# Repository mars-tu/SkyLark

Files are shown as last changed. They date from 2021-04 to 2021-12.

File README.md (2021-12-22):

# SkyLark
Repository of Drone named SkyLark by MARS capable of autonomous navigation for transfer of goods.

## Key Feature:-
* Autonomous robot with payload to carry for multiple purposes which is capable to move on RC control.
* Manipulate flight by gesture recognition.
* Runs on PX4 AutoPilot framework via ROS.

## Electro-mechanical design:

* Drone frame.
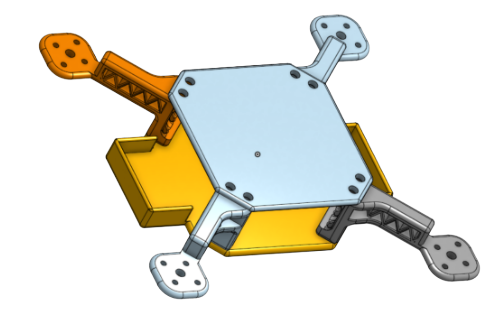
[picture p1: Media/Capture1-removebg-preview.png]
Image alt text Drone frame


## Flight Controller Schematic:
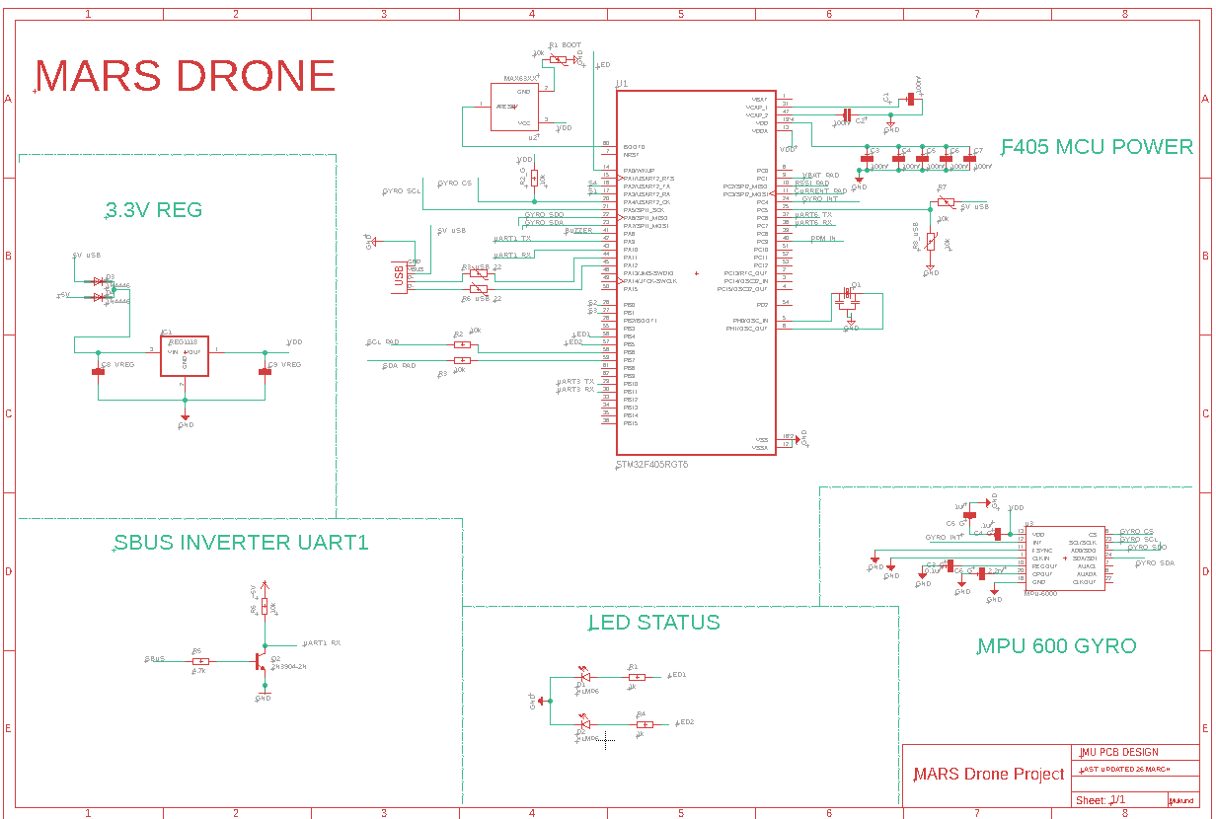
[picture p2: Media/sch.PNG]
Image alt text Schematic


## ROS Packages:
* [SkyLark package](#flying_skylark)

### flying_skylark
------------------
* This package contains all the files related to robot and its configuration 

### Setup and launching the simulation environment:-

* Clone the repo, build in your preferred system and add the following lines in your bashrc.
```
source ~/{name_of_workspace}/devel/setup.bash

source ~/{name_of_workspace}/src/PX4-Autopilot/Tools/setup_gazebo.bash ~/{name_of_workspace}/src/PX4-Autopilot/ ~/{name_of_workspace}/src/PX4-Autopilot/build/px4_sitl_default >> /dev/null

export ROS_PACKAGE_PATH=$ROS_PACKAGE_PATH:~/{name_of_workspace}/src/PX4-Autopilot

export ROS_PACKAGE_PATH=$ROS_PACKAGE_PATH:~/{name_of_workspace}/src/PX4-Autopilot/Tools/sitl_gazebo

```
* For making gazebo work with PX-4 autopilot 
```
cd ~/{name_of_workspace}/src/PX4-Autopilot/
make px4_sitl_default gazebo
```

* Command `roslaunch flying_skylark flying_square.launch` will launch the gazebo world along with the PX-4 autopilot.

### Simulation Video
Click on Image to play
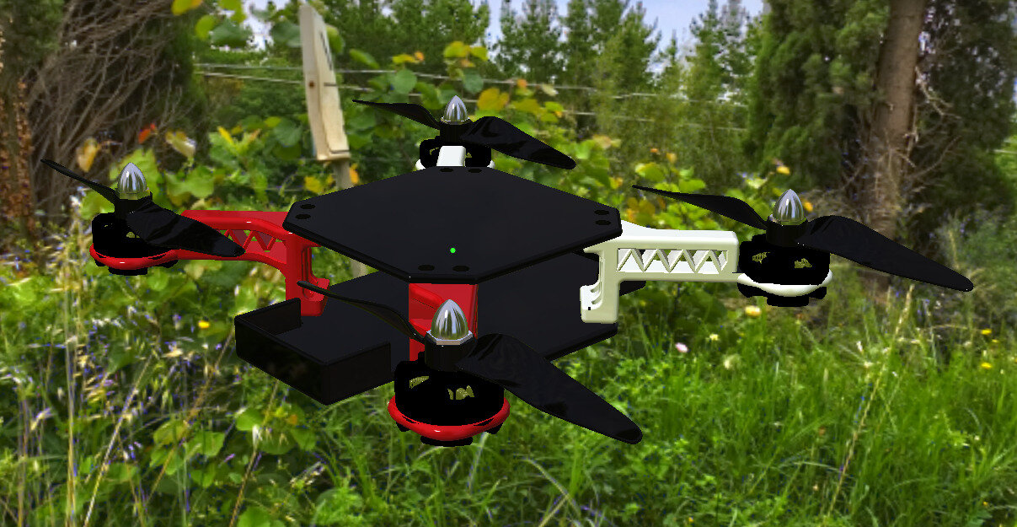
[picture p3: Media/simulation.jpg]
Watch the video (https://drive.google.com/file/d/1lU4UtkTPGOdcDK2UvRqbzy2OsXT-8WxJ/view?usp=sharing)


## Prerequisites
* C++14
* python 2.x
* PX4 AutoPilot
* ROS Noetic
* Embedded C
* Raspberry pi 3B (setup given below)
* Eagle
* PTC Creo
#### Note: Hardware prerequisites mentioned in xyz section.

## Setup
* [Raspi + OS setup](#setting-up-cpu)

### Setting Up CPU
------------------
#### Installing Ubuntu and ROS on Raspberry pi
1) [Download](https://cdimage.ubuntu.com/releases/18.04/release/) the Ubuntu image for raspberry pi 3.
2) Flash the image with preferable software.
3) Follow the standard ARM installation instructions from [ROS Wiki](https://wiki.ros.org/melodic/Installation/Ubuntu) to install ROS Melodic.

#### Installing basic tools and setting them up
```
sudo apt-get update
sudo apt-get upgrade
sudo apt autoremove
```

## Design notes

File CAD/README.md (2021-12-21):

## ITERATION 1:

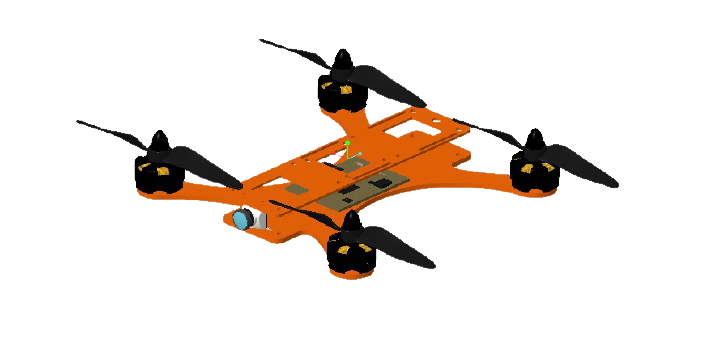
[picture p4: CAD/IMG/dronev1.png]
Image alt text Drone frame 1st Iteration


Flaws in Iteration 1 are: 
1. If the drone were to drop for a height, the whole would get damaged and will have to be replaced making it cost ineffective. 
2. There isn't enough space for electronics components.

## Analysis of Model 1:
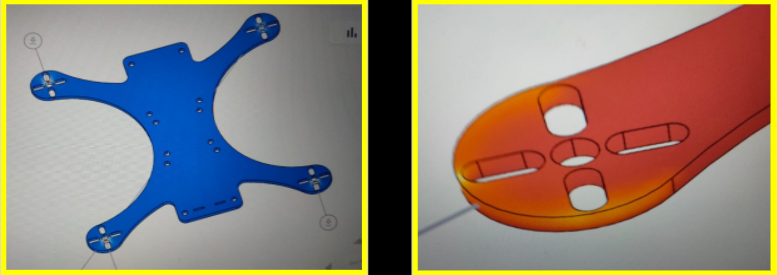
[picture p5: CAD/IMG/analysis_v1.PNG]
Image alt text Drone frame 1 Analysis


## ITERATION 2:

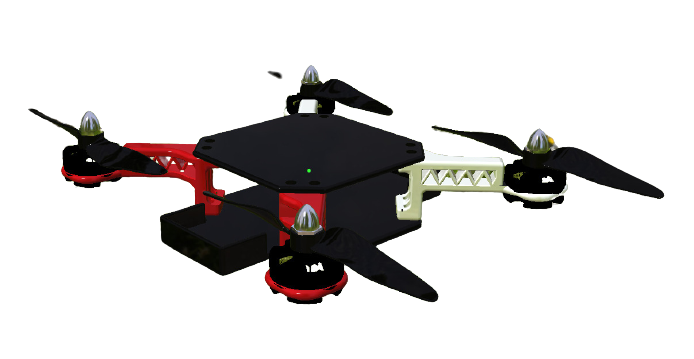
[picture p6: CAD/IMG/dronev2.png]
Image alt text Drone frame 2nd Iteration


Flaws in Iteration 2 are:
1. There can be more optimisation in weight done.
2. Final analysis isn't complete such as drop test and cfd.

## Analysis of Model 1:

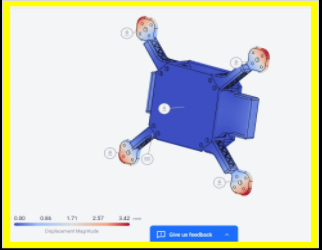
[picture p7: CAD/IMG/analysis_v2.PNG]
Image alt text Drone frame 2 Analysis


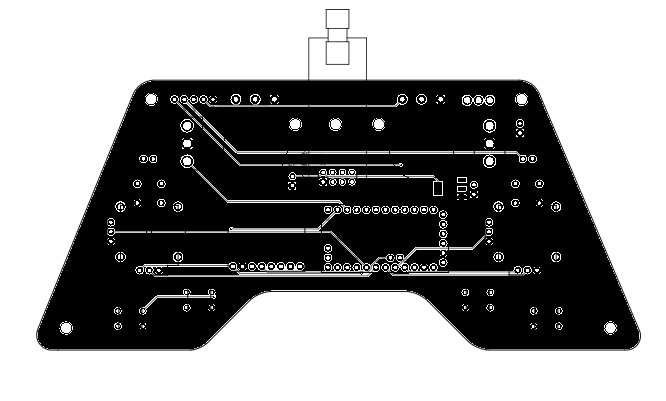
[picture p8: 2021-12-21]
Electronics/Control Unit/Transmitter V2/PCB_Transmitter V2_2021-06-21.png

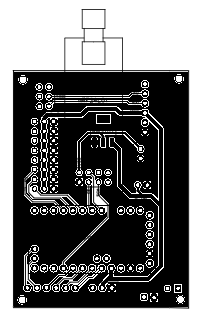
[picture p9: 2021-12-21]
Electronics/Control Unit/Reciver/PCB_Reciver v1_2021-06-21.png

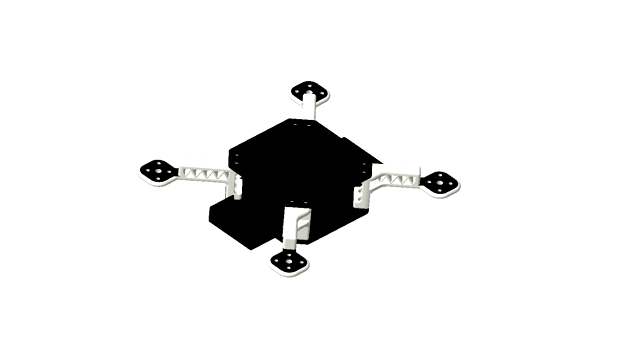
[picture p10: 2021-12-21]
Media/FRAME_V2.gif

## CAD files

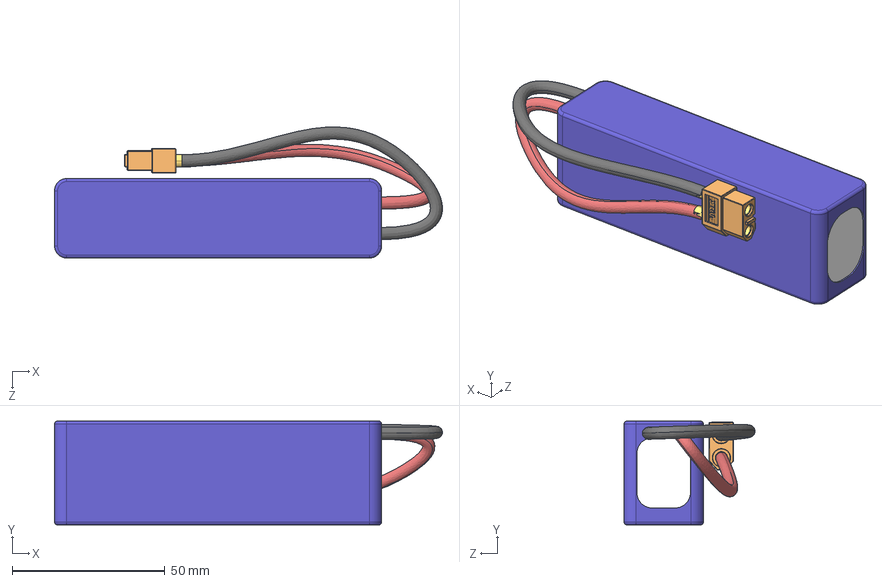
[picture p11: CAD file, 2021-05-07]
CAD/Initial Basic Parts/Assembly_Multistar_Battery_3000mah.STEP
126.9 x 34.0 x 42.9 mm
Multistar_3000mAh_4S_Lipo_Battery
XT60 Buchse
Part3^Assembly_Multistar_Battery_3000mah

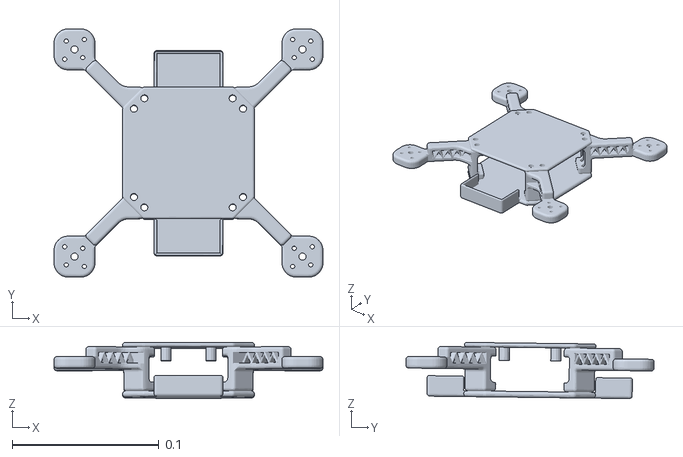
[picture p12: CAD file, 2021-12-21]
src/skylark/flying_skylark/meshes/base_link.STL
0.184 x 0.169 x 0.0383

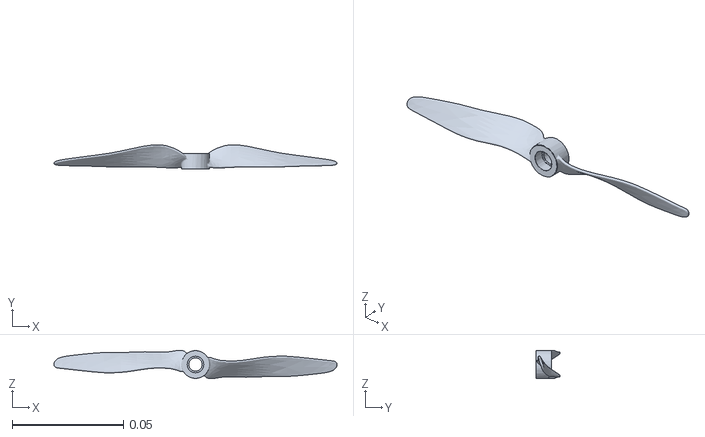
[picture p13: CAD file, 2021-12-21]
src/skylark/flying_skylark/meshes/Link_1.STL
0.127 x 0.0109 x 0.0127

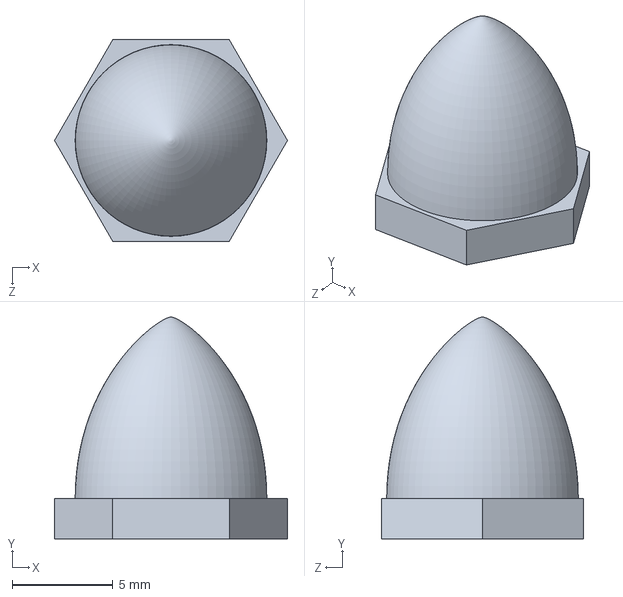
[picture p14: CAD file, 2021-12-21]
CAD/Initial Basic Parts/emax-mt2204-2300kv-dc-motor-brushless-for-fpv-quadcopter-1.snapshot.5/Emax MT 2204-2300KV/01000A-010-001-PN.SLDPRT
11.5 x 11.0 x 10.0 mm

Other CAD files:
src/skylark/flying_skylark/meshes/Link_4.STL
src/skylark/flying_skylark/meshes/Link_3.STL

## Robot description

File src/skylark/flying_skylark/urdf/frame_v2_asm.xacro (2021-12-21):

<?xml version="1.0" encoding="utf-8"?>
<!-- This URDF was automatically created by SolidWorks to URDF Exporter! Originally created by Stephen Brawner (brawner@gmail.com) 
     Commit Version: 1.6.0-1-g15f4949  Build Version: 1.6.7594.29634
     For more information, please see http://wiki.ros.org/sw_urdf_exporter -->
<robot name="frame_v2_asm" xmlns:xacro="http://www.ros.org/wiki/xacro">
 

 <link name="base_link">
    <inertial>
      <origin xyz="0 0 0" rpy="0 0 0" />
      <mass value="0.1411" />
      <inertia ixx="9.5842E-05" ixy="5.841E-09" ixz="-2.8656E-09" iyy="5.8076E-05" iyz="1.0736E-06" izz="0.00014791" />
    </inertial>
    <visual>
      <origin xyz="0 0 0" rpy="0 0 0" />
      <geometry>
        <mesh filename="package://flying_skylark/meshes/base_link.STL" />
      </geometry>
      <material name="">
        <color rgba="0.75294 0.75294 0.75294 1" />
      </material>
    </visual>
    <collision>
      <origin xyz="0 0 0" rpy="0 0 0" />
      <geometry>
        <mesh filename="package://flying_skylark/meshes/base_link.STL" />
      </geometry>
    </collision>
  </link>

  <gazebo reference="base_link">
    <material>Gazebo/Grey</material>
  </gazebo>

  <link name="Link_1">
    <inertial>
      <origin xyz="3.2072E-07 0.0042783 -1.4373E-07" rpy="0 0 0" />
      <mass value="0.0017578" />
      <inertia ixx="2.4709E-08" ixy="-1.4479E-12" ixz="4.0373E-08" iyy="1.3863E-06" iyz="1.1197E-12" izz="1.3791E-06" />
    </inertial>
    <visual>
      <origin xyz="0 0 0" rpy="0 0 0" />
      <geometry>
        <mesh filename="package://flying_skylark/meshes/Link_1.STL" />
      </geometry>
      <material name="">
        <color rgba="0 0 1 1" />
      </material>
    </visual>
    <collision>
      <origin xyz="0 0 0" rpy="0 0 0" />
      <geometry>
        <mesh filename="package://flying_skylark/meshes/Link_1.STL" />
      </geometry>
    </collision>
  </link>

  <gazebo reference="Link_1">
    <material>Gazebo/Blue</material>
  </gazebo>

  <joint name="Prop_1" type="revolute">
    <origin xyz="-0.080221 -0.061832 0.008502" rpy="1.5588 0 0" />
    <parent link="base_link" />
    <child link="Link_1" />
    <axis xyz="0 1 0" />
    <limit lower="-3.14" upper="3.14" effort="0" velocity="0" />
  </joint>



  <link name="Link_2">
    <inertial>
      <origin xyz="3.2072E-07 0.0042783 -1.4373E-07" rpy="0 0 0" />
      <mass value="0.0017578" />
      <inertia ixx="2.4709E-08" ixy="-1.4479E-12" ixz="4.0373E-08" iyy="1.3863E-06" iyz="1.1197E-12" izz="1.3791E-06" />
    </inertial>
    <visual>
      <origin xyz="0 0 0" rpy="0 0 0" />
      <geometry>
        <mesh filename="package://flying_skylark/meshes/Link_2.STL" />
      </geometry>
      <material name="">
        <color rgba="0 0 1 1" />
      </material>
    </visual>
    <collision>
      <origin xyz="0 0 0" rpy="0 0 0" />
      <geometry>
        <mesh filename="package://flying_skylark/meshes/Link_2.STL" />
      </geometry>
    </collision>
  </link>

  <gazebo reference="Link_2">
    <material>Gazebo/Blue</material>
  </gazebo>


  <joint name="Prop_2" type="revolute">
    <origin xyz="0.075342 -0.061832 0.008502" rpy="1.5588 0 0" />
    <parent link="base_link" />
    <child link="Link_2" />
    <axis xyz="0 1 0" />
    <limit lower="-3.14" upper="3.14" effort="0" velocity="0" />
  </joint>



  <link name="Link_3">
    <inertial>
      <origin xyz="2.9874E-07 0.0042783 -1.4713E-07" rpy="0 0 0" />
      <mass value="0.0017578" />
      <inertia ixx="2.4709E-08" ixy="-1.4714E-12" ixz="4.0373E-08" iyy="1.3863E-06" iyz="1.1066E-12" izz="1.3791E-06" />
    </inertial>
    <visual>
      <origin xyz="0 0 0" rpy="0 0 0" />
      <geometry>
        <mesh filename="package://flying_skylark/meshes/Link_3.STL" />
      </geometry>
      <material name="">
        <color rgba="0.79216 0.81961 0.93333 1" />
      </material>
    </visual>
    <collision>
      <origin xyz="0 0 0" rpy="0 0 0" />
      <geometry>
        <mesh filename="package://flying_skylark/meshes/Link_3.STL" />
      </geometry>
    </collision>
  </link>

  <gazebo reference="Link_3">
    <material>Gazebo/Grey</material>
  </gazebo>


  <joint name="Prop_3" type="revolute">
    <origin xyz="0.075342 0.079769 0.014502" rpy="-1.5653 -0.01064 -2.0478" />
    <parent link="base_link" />
    <child link="Link_3" />
    <axis xyz="0 1 0" />
    <limit lower="-3.14" upper="3.14" effort="0" velocity="0" />
  </joint>



  <link name="Link_4">
    <inertial>
      <origin xyz="-0.0024512 0.0087826 -0.0086882" rpy="0 0 0" />
      <mass value="0.1411" />
      <inertia ixx="9.5842E-05" ixy="5.841E-09" ixz="-2.8656E-09" iyy="5.8076E-05" iyz="1.0736E-06" izz="0.00014791" />
    </inertial>
    <visual>
      <origin xyz="0 0 0" rpy="0 0 0" />
      <geometry>
        <mesh filename="package://flying_skylark/meshes/Link_4.STL" />
      </geometry>
      <material name="">
        <color rgba="0.75294 0.75294 0.75294 1" />
      </material>
    </visual>
    <collision>
      <origin xyz="0 0 0" rpy="0 0 0" />
      <geometry>
        <mesh filename="package://flying_skylark/meshes/Link_4.STL" />
      </geometry>
    </collision>
  </link>

  <gazebo reference="Link_4">
    <material>Gazebo/Grey</material>
  </gazebo>

  <joint name="Prop_4" type="revolute">
    <origin xyz="-0.080221 0.079578 0.008502" rpy="1.5828 4.3744E-05 3.1379" />
    <parent link="base_link" />
    <child link="Link_4" />
    <axis xyz="0 1 0" />
    <limit lower="-3.14" upper="3.14" effort="0" velocity="0" />
  </joint>

 <!--add lidar-->
        <!-- <link name="hokuyo_link">
          <pose>0 0 0 0 0 0</pose>
          <collision name="collision">
            <pose>0 0 0.3 0 0 0</pose>
            <geometry>
              <box>
                <size>0.1 0.1 0.1</size>
              </box>
            </geometry>
          </collision>
          <visual name="visual">
            <pose>0 0 0.27 0 0 0</pose>
            <geometry>
              <mesh filename="package://flying_skylark/meshes/hokuyo.dae">
              </mesh>
            </geometry>
          </visual>
          <inertial>
            <mass value="0.016"/>
               low intertia necessary to avoid not disturb the drone
            <inertia ixx="0.0001" ixy="0" ixz="0" iyy="0.0001" iyz="0" izz="0.0001" />
          </inertial>
          </link> -->

    
        <!-- <joint name="hokuyo_joint" type="fixed">
          <pose>0 0 0 0 0 0</pose>
          <parent link="base_link"/>
          <child link="hokuyo_link"/>
        </joint> -->
</robot>

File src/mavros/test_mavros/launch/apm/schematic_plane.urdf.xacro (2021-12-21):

<?xml version="1.0" encoding="UTF-8"?>
<robot xmlns:xacro="http://www.ros.org/wiki/xacro" name="schematic_plane">

  <!--
       This file creates schematic model of plane.
       Sizes based on Skywalker 1900.
       -->

  <xacro:property name="kgcm_to_nm" value="0.0980665" />

  <!-- materials -->

  <material name="dark-grey">
    <color rgba=".2 .2 .2 1" />
  </material>
  <material name="grey">
    <color rgba=".6 .6 .6 1" />
  </material>
  <material name="red">
    <color rgba=".9 0 0 1" />
  </material>
  <material name="green">
    <color rgba="0 .9 0 1" />
  </material>
  <material name="blue">
    <color rgba="0 0 .9 1" />
  </material>
  <material name="yellow">
    <color rgba=".9 .9 0 1" />
  </material>

  <!-- base_link -->

  <link name="base_link">
    <!-- Robot base link: near CoG -->
    <!-- look <visual> at rarog_description -->
  </link>

  <link name="fcu">
    <!-- FCU frame (mavros uses this link for most topics) -->
    <visual>
      <geometry>
        <!-- Pixhawk -->
        <box size=".085 .052 .02" />
      </geometry>
      <material name="dark-grey" />
    </visual>
  </link>
  <joint name="base_to_fcu" type="fixed">
    <parent link="base_link" />
    <child link="fcu" />
    <!-- FCU located under wing, on symmetry line,
         +5 cm X, -3 cm Y from base_link
         -->
    <origin xyz="0.05 0 -0.03" rpy="0 0 0" />
  </joint>

  <!-- fuselage (simple geometric figures) -->

  <link name="tail_link">
    <visual>
      <geometry>
        <cylinder length="1.10" radius=".025" />
      </geometry>
      <material name="grey" />
    </visual>
  </link>
  <joint name="base_to_tail" type="fixed">
    <parent link="base_link" />
    <child link="tail_link" />
    <origin xyz="${1.10/2 - .70} 0 -.15" rpy="0 ${pi/2} 0" />
  </joint>

  <link name="wing_link">
    <visual>
      <geometry>
        <box size=".20 1.9 .01" />
      </geometry>
      <material name="grey" />
    </visual>
  </link>
  <joint name="base_to_wing" type="fixed">
    <parent link="base_link" />
    <child link="wing_link" />
    <origin xyz=".05 0 .02" rpy="0 0 0" />
  </joint>

  <link name="tailplane_link">
    <visual>
      <geometry>
        <box size=".10 .61 .01" />
      </geometry>
      <material name="grey" />
    </visual>
  </link>
  <joint name="base_to_tailplane" type="fixed">
    <parent link="base_link" />
    <child link="tailplane_link" />
    <origin xyz="-0.70 0 .07" rpy="0 0 0" />
  </joint>

  <link name="fin_link">
    <visual>
      <geometry>
        <box size=".12 .01 .20" />
      </geometry>
      <material name="grey" />
    </visual>
  </link>
  <joint name="base_to_fin" type="fixed">
    <parent link="base_link" />
    <child link="fin_link" />
    <origin xyz="${-0.71 + .12/2} 0 ${-0.15/2 + .05}" rpy="0 0 0" />
  </joint>

  <!-- control surfaces -->

  <xacro:macro name="common_servo_limit">
      <!-- Lets say 30 deg, servo: 1.5 kg*cm (6 volt), 60 deg in 0.10 sec -->
      <limit lower="${radians(-30)}" upper="${radians(30)}" effort="${1.5 * kgcm_to_nm}" velocity="${radians(60. / 0.10)}" />
  </xacro:macro>

  <xacro:macro name="aileron" params="link *material *origin *mimic">
    <link name="${link}">
      <visual>
        <geometry>
          <box size=".055 .245 .005" />
        </geometry>
        <xacro:insert_block name="material" />
        <origin xyz="${-0.055/2} 0 0" rpy="0 0 0" />
      </visual>
    </link>

    <joint name="${link}" type="revolute">
      <parent link="base_link" />
      <child link="${link}" />
      <xacro:insert_block name="origin" />
      <axis xyz="0 1 0" />
      <xacro:common_servo_limit />
      <xacro:insert_block name="mimic" />
    </joint>
  </xacro:macro>

  <!-- conventional ailerons controlled by one axis -->
  <link name="aileron_link" />
  <joint name="aileron" type="revolute">
    <parent link="base_link" />
    <child link="aileron_link" />
    <xacro:common_servo_limit />
  </joint>

  <!-- aileron location: 51 cm Y to 6-cm side, -5 cm on X -->
  <xacro:aileron link="aileron_left">
    <material name="red" />
    <origin xyz="-0.05 ${.51 + .245/2} .02" rpy="0 0 0" />
    <mimic joint="aileron" multiplier="-1" />
  </xacro:aileron>
  <xacro:aileron link="aileron_right">
    <material name="green" />
    <origin xyz="-0.05 ${-(.51 + .245/2)} .02" rpy="0 0 0" />
    <mimic joint="aileron" multiplier="1" />
  </xacro:aileron>

  <!-- Elevator (T-tail) -->
  <link name="elevator_link">
    <visual>
      <geometry>
        <box size=".035 .54 .005" />
      </geometry>
      <material name="blue" />
      <origin xyz="${-0.035/2} 0 0" rpy="0 0 0" />
    </visual>
  </link>
  <joint name="elevator" type="revolute">
    <parent link="base_link" />
    <child link="elevator_link" />
    <origin xyz="-0.75 0 .07" rpy="0 0 0" />
    <axis xyz="0 1 0" />
    <xacro:common_servo_limit />
  </joint>

  <!-- Rudder (T-tail) -->
  <link name="rudder_link">
    <visual>
      <geometry>
        <box size=".07 .005 .165" />
      </geometry>
      <material name="yellow" />
      <origin xyz="${-0.07/2} 0 0" rpy="0 0 0" />
    </visual>
  </link>
  <joint name="rudder" type="revolute">
    <parent link="base_link" />
    <child link="rudder_link" />
    <origin xyz="-0.71 0 -0.05" rpy="0 0 0" />
    <axis xyz="0 0 1" />
    <xacro:common_servo_limit />
  </joint>

  <!-- vim: set ts=2 sw=2 et : -->
</robot>

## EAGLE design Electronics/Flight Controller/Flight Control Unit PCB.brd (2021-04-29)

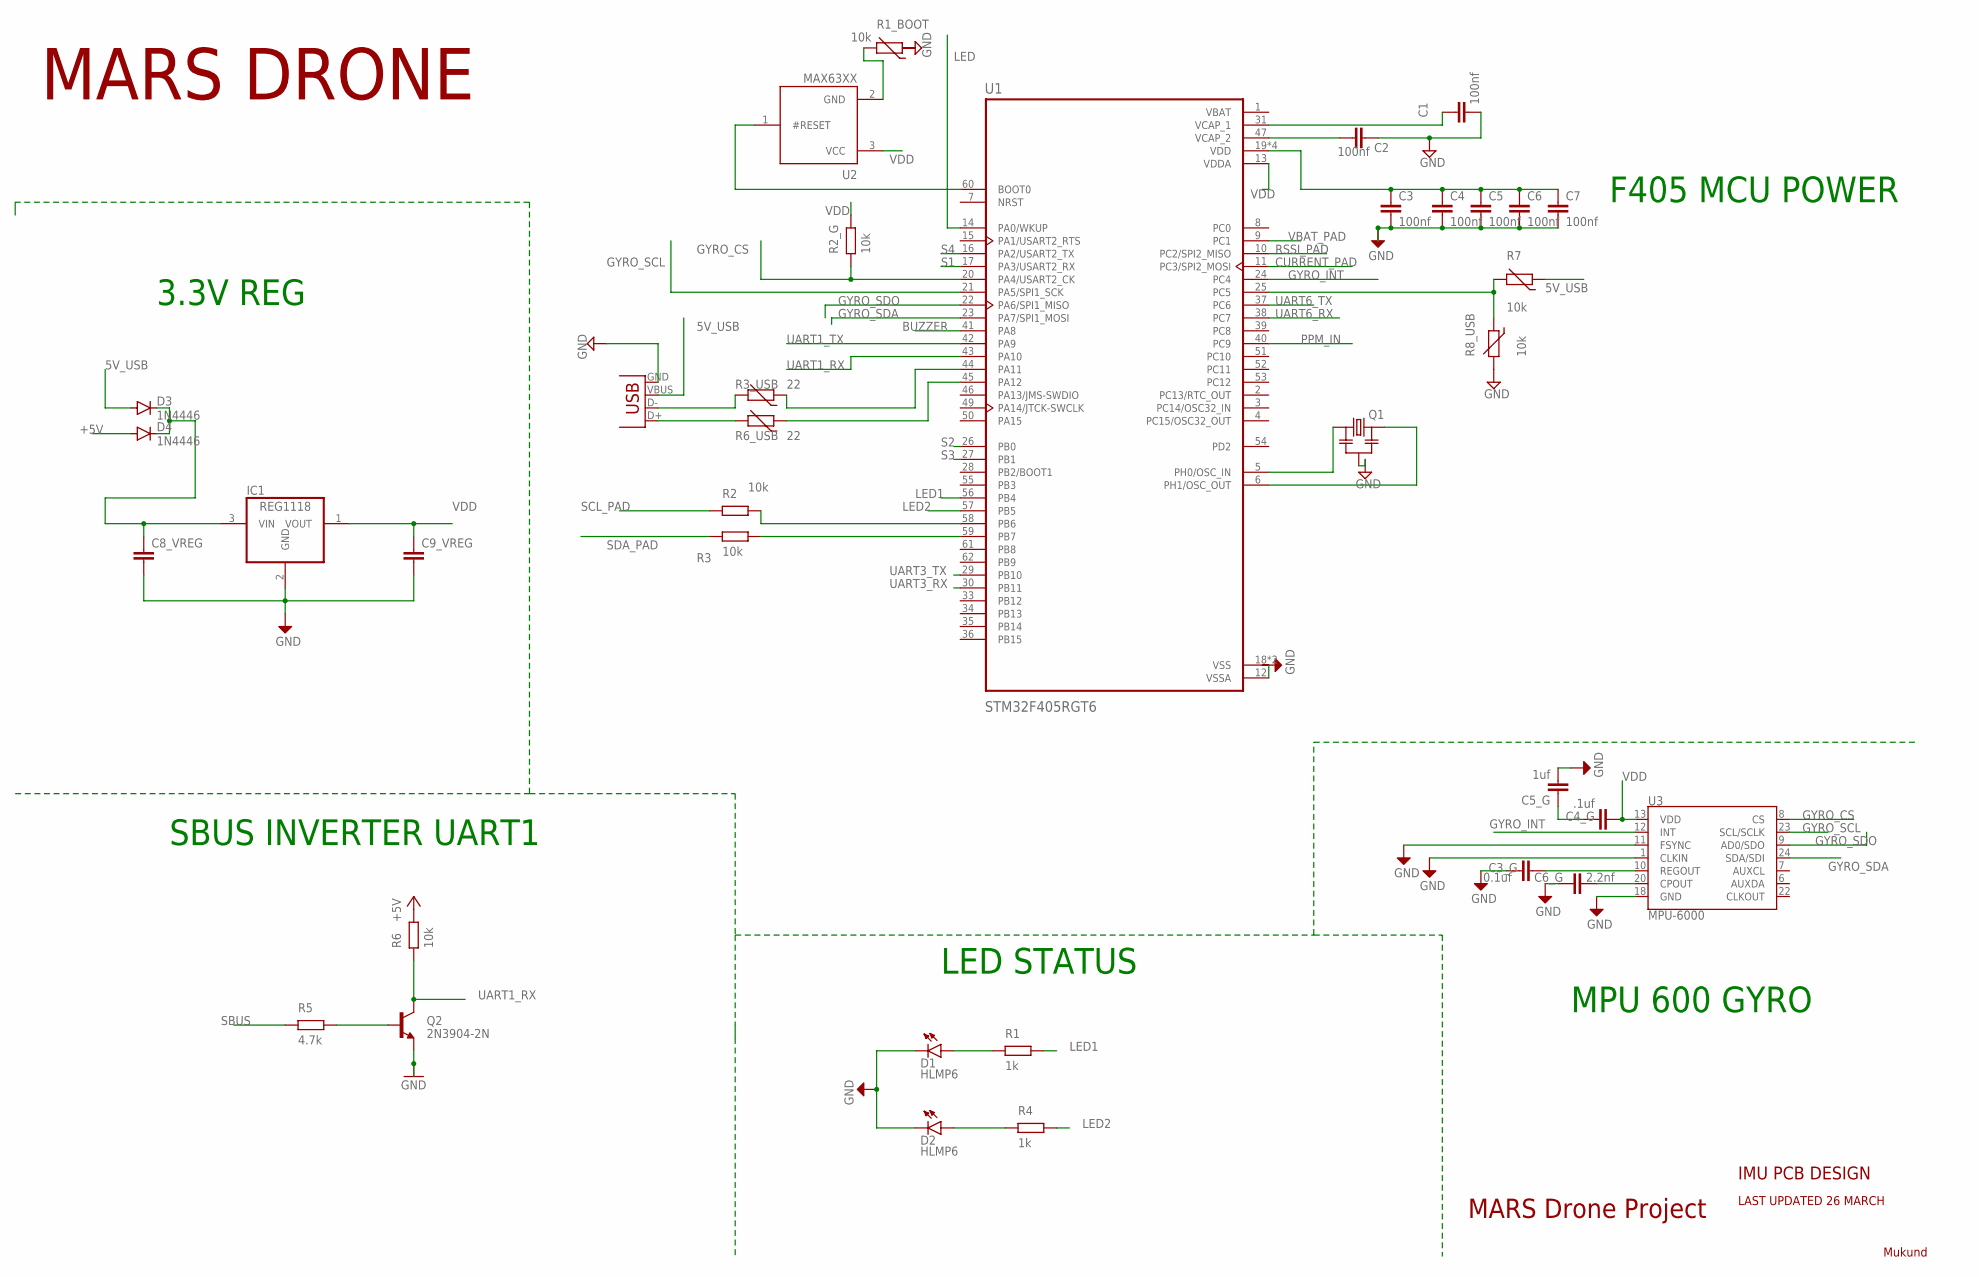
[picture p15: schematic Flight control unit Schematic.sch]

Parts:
C1, C2: 100nf; C2.5-3
C3, C4, C5, C6, C7: 100nf; C2.5-2
C3_G: 0.1uf; C2.5-3
C4_G: .1uf; C2.5-3
C5_G: 1uf; C2.5-3
C6_G: 2.2nf; C2.5-3
C8_VREG, C9_VREG: C2,5-3; C2.5-3
D1, D2: HLMP6
D3, D4: 1N4446; DO35-10
IC1: REG1118; SOT223
Q1: RESONATOR-MURATACST_CE; RESONATOR_MURATA2
Q2: 2N3904-2N; TO92
R1_BOOT, R7, R8_USB: 10k; RS-2,5
R3_USB, R6_USB: 22; RS-2,5
U1: STM32F405RGT6; QFP50P1200X1200X160-64N
U2: MAX63XX; SOT23
U3: MPU-6000; QFN-24-EP
X1: USB-A-S

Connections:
5V_USB: D3.A, R7.1, X1.VBUS
+5V: D4.A
BUZZER: U1.41 (PA8)
CURRENT_PAD: U1.11 (PC3/SPI2_MOSI)
GND: C1.2, C2.2, C3.2, C3_G.1, C4.2, C5.2, C5_G.2, C6.2, C6_G.1, C7.2, C8_VREG.2, C9_VREG.2, D1.K, D2.K, IC1.2 (GND), Q1.2, Q2.3 (E), R8_USB.2, U3.1 (CLKIN), U3.11 (FSYNC), U3.18 (GND), X1.GND
GYRO_CS: U1.20 (PA4/USART2_CK), U3.8 (CS)
GYRO_INT: U1.24 (PC4), U3.12 (INT)
GYRO_SCL: U1.21 (PA5/SPI1_SCK), U3.23 (SCL/SCLK)
GYRO_SDA: U1.23 (PA7/SPI1_MOSI), U3.24 (SDA/SDI)
GYRO_SDO: U1.22 (PA6/SPI1_MISO), U3.9 (AD0/SDO)
LED: U1.14 (PA0/WKUP)
LED1: U1.56 (PB4)
LED2: U1.57 (PB5)
unnamed: C6_G.2, U3.20 (CPOUT)
unnamed: U1.12 (VSSA), U1.18 (VSS), U1.63 (VSS)
unnamed: C4_G.1, C5_G.1
unnamed: C3.1, C4.1, C5.1, C6.1, C7.1, U1.19 (VDD), U1.32 (VDD), U1.48 (VDD), U1.64 (VDD)
unnamed: C3_G.2, U3.10 (REGOUT)
unnamed: R3_USB.1, U1.44 (PA11)
unnamed: R6_USB.1, U1.45 (PA12)
unnamed: C8_VREG.1, D3.C, D4.C, IC1.3 (VIN)
unnamed: R7.2, R8_USB.1, U1.25 (PC5)
unnamed: C1.1, U1.31 (VCAP_1)
unnamed: C2.1, U1.47 (VCAP_2)
unnamed: U1.60 (BOOT0), U2.1 (#RESET)
unnamed: R1_BOOT.2, U2.2 (GND)
unnamed: R6_USB.2, X1.D+
unnamed: R3_USB.2, X1.D-
unnamed: Q1.1, U1.5 (PH0/OSC_IN)
unnamed: Q1.3, U1.6 (PH1/OSC_OUT)
PPM_IN: U1.40 (PC9)
RSSI_PAD: U1.10 (PC2/SPI2_MISO)
S1: U1.17 (PA3/USART2_RX)
S2: U1.26 (PB0)
S3: U1.27 (PB1)
S4: U1.16 (PA2/USART2_TX)
UART1_RX: Q2.1 (C), U1.43 (PA10)
UART1_TX: U1.42 (PA9)
UART3_RX: U1.30 (PB11)
UART3_TX: U1.29 (PB10)
UART6_RX: U1.38 (PC7)
UART6_TX: U1.37 (PC6)
VBAT: U1.1 (VBAT)
VBAT_PAD: U1.9 (PC1)
VDD: C4_G.2, C9_VREG.1, IC1.1 (VOUT), U1.13 (VDDA), U2.3 (VCC), U3.13 (VDD)

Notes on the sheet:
F405 MCU POWER
MPU 600 GYRO
LED STATUS
SBUS INVERTER UART1
3.3V REG
LAST UPDATED 26 MARCH
MARS Drone Project
IMU PCB DESIGN
Mukund
MARS DRONE

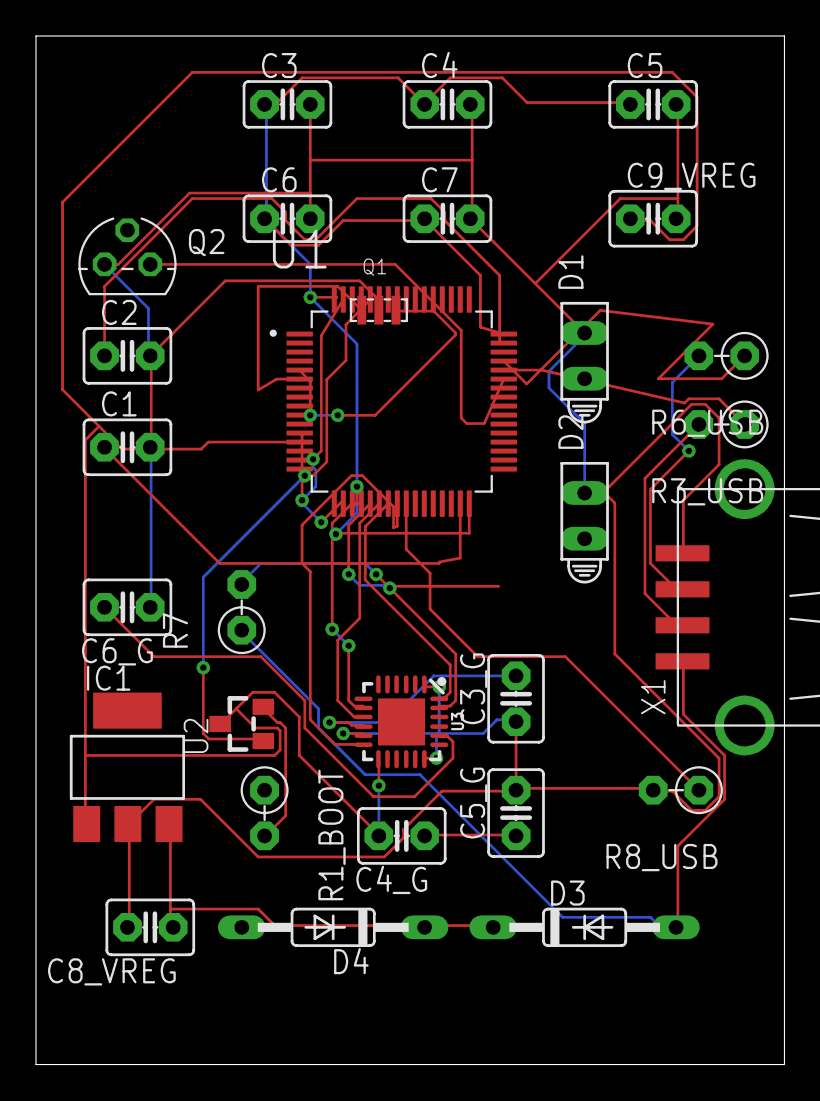
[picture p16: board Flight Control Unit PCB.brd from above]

Board: 2 copper layers, 41.6 x 57.1 mm, 29 parts (0 on the bottom side), 26 nets.

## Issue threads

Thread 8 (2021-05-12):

Drop damage to the Frame

sarthak563, 2021-05-12:
If our quad-copter drops from an height then there is a tendency that the whole frame will break and we will have to replace the whole frame causing us to repeat the costs.

mars-tu, 2021-07-22:
New Frame created

Closed 2021-07-22.

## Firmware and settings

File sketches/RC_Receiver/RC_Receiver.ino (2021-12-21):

/*
   Arduino RC Receiver - MI-4
   by MARS Robotics Society, Thapar University, Patiala
   [Ayushman Bedi, Mukund Gupta]
   https://github.com/mars-tu/MI-4
*/
#include <SPI.h>
#include <RF24.h>
#include <nRF24L01.h>
#include <Servo.h>
#define enA 9  // Arduino pin D9 - CH6 on PCB board - PWM output
#define in1 8  // D8 - CH5
#define in2 7  // D7 - CH4
#define in3 6  // D6 - CH3 
#define in4 4  // D4 - CH1 
#define enB 5  // D5 - CH2 - PWM output
#define in5 3  // D10 - CH7
#define in6 2  // D11 - CH8

Servo sClaw;
Servo sJoint;
int clawValue, jointValue;
RF24 radio(3, 2);   // nRF24L01 (CE, CSN)
const byte address[6] = "00001";
unsigned long lastReceiveTime = 0;
unsigned long currentTime = 0;

// Max size of this struct is 32 bytes
struct Data_Package {
  byte j1PotX;
  byte j1PotY;
  byte j1Button;
  byte j2PotX;
  byte j2PotY;
  byte j2Button;
  byte pot1;
  byte pot2;
  byte tSwitch1;
  byte tSwitch2;
  byte button1;
  byte button2;
  byte button3;
  byte button4;
};
Data_Package data; //Creating a variable with the above structure
int  steering, throttle, lift, claw, up, down;
int motorSpeedA = 0;
int motorSpeedB = 0;
int motorClimbA = 0;
int motorClimbB = 0;
void setup() { 
  //car motors
  pinMode(enA, OUTPUT);
  pinMode(enB, OUTPUT);
  pinMode(in1, OUTPUT);
  pinMode(in2, OUTPUT);
  pinMode(in3, OUTPUT);
  pinMode(in4, OUTPUT);
  //servo motors
  pinMode(in5, OUTPUT);
  pinMode(in6, OUTPUT);
  //climbing motors
  pinMode(A0, OUTPUT);
  pinMode(A1, OUTPUT);
  pinMode(A2, OUTPUT);
  pinMode(A3, OUTPUT);
  pinMode(A4, OUTPUT);
  pinMode(A5, OUTPUT);
  //Serial.begin(9600);
  radio.begin();
  radio.openReadingPipe(0, address);
  radio.setAutoAck(false);
  radio.setDataRate(RF24_250KBPS);
  radio.setPALevel(RF24_PA_LOW);
  radio.startListening(); //  Set the module as receiver
  resetData();
  sClaw.attach(in5); // D10 - CH7
  sJoint.attach(in6); // D11 - CH8
}
void loop() {

  // Check whether we keep receving data, or we have a connection between the two modules
  currentTime = millis();
  if ( currentTime - lastReceiveTime > 1000 ) { // If current time is more then 1 second since we have recived the last data, that means we have lost connection
    resetData(); // If connection is lost, reset the data. It prevents unwanted behavior.
  }
  // Check whether there is data to be received
  if (radio.available()) {
    radio.read(&data, sizeof(Data_Package)); // Read the whole data and store it into the 'data' structure
    lastReceiveTime = millis(); // At this moment we have received the data
  }
  
  // Parse the data from the Joystic 1 to the throttle and steering variables
  throttle = data.j1PotY;
  steering = data.j1PotX;
  
  // Throttle used for forward and backward control
  // Joystick values: 0 to 255; down = 0; middle = 127; up = 255
  if (throttle < 110) {
    // Set Motor A backward
    digitalWrite(in1, HIGH);
    digitalWrite(in2, LOW);
    // Set Motor B backward
    digitalWrite(in3, HIGH);
    digitalWrite(in4, LOW);
    // Convert the declining throttle readings for going backward from 110 to 0 into 0 to 255 value for the PWM signal for increasing the motor speed
    motorSpeedA = map(throttle, 110, 0, 0, 255);
    motorSpeedB = map(throttle, 110, 0, 0, 255);
  }
  else if (throttle > 140) {
    // Set Motor A forward
    digitalWrite(in1, LOW);
    digitalWrite(in2, HIGH);
    // Set Motor B forward
    digitalWrite(in3, LOW);
    digitalWrite(in4, HIGH);
    // Convert the increasing throttle readings for going forward from 140 to 255 into 0 to 255 value for the PWM signal for increasing the motor speed
    motorSpeedA = map(throttle, 140, 255, 0, 255);
    motorSpeedB = map(throttle, 140, 255, 0, 255);
  }
  // If joystick stays in middle the motors are not moving
  else {
    motorSpeedA = 0;
    motorSpeedB = 0;
  }
  // Steering used for left and right control
  if (steering < 110) {
    // Convert the declining steering readings from 140 to 255 into increasing 0 to 255 value
    int xMapped = map(steering, 110, 0, 0, 255);
    // Move to left - decrease left motor speed, increase right motor speed
    motorSpeedA = motorSpeedA - xMapped;
    motorSpeedB = motorSpeedB + xMapped;
    // Confine the range from 0 to 255
    if (motorSpeedA < 0) {
      motorSpeedA = 0;
    }
    if (motorSpeedB > 255) {
      motorSpeedB = 255;
    }
  }
  if (steering > 140) {
    // Convert the increasing steering readings from 110 to 0 into 0 to 255 value
    int xMapped = map(steering, 140, 255, 0, 255);
    // Moving right
    motorSpeedA = motorSpeedA + xMapped;
    motorSpeedB = motorSpeedB - xMapped;
    // Confine the range from 0 to 255
    if (motorSpeedA > 255) {
      motorSpeedA = 255;
    }
    if (motorSpeedB < 0) {
      motorSpeedB = 0;
    }
  }
  // Prevent buzzing at low speeds (We can adjust according to the Result)
  if (motorSpeedA < 70) {
    motorSpeedA = 0;
  }
  if (motorSpeedB < 70) {
    motorSpeedB = 0;
  }

  
  // Controlling servos for the Arm of the robot using Joystick 2
  claw = data.button3;
  lift = data.j2PotY;
  // Joystick values: 0 to 255; down = 0; middle = 127; up = 255
  // Joystick 2  for lifting the object
  if (lift < 110) {
    jointValue = map(lift, 0, 255, 0, 180);    // Changing angles accordingly
  }
  if(lift > 140){
    jointValue = map(lift, 0, 255, 0, 180);    // Changing angles accordingly
  }
  
  if (claw == 1) {
    clawValue = map(lift, 0, 255, 0, 180);    // Changing angles accordingly
  }
  if(claw == 0){
    clawValue = map(lift, 0, 255, 0, 180);    // Changing angles accordingly
  }

  //Climbing mechanism
  up = data.button1;
  down = data.button2;
  
  if(up == 1){
    // Set Climb Motor A clockwise
    analogWrite(A3, HIGH);
    analogWrite(A4, LOW);
    // Set Climb Motor B anti-cloclwise
    analogWrite(A5, LOW);
    analogWrite(A6, HIGH);

  }else{
    analogWrite(A3, LOW);
    analogWrite(A4, LOW);
    analogWrite(A5, LOW);
    analogWrite(A6, LOW);
  }
  if(down == 1){
    // Set Climb Motor A anti-clockwise
    digitalWrite(A3, LOW);
    digitalWrite(A4, HIGH);
    // Set Climb Motor B cloclwise
    digitalWrite(A5, HIGH);
    digitalWrite(A6, LOW);
  }else{
    digitalWrite(A3, LOW);
    digitalWrite(A4, LOW);
    digitalWrite(A5, LOW);
    digitalWrite(A6, LOW);
  }
  motorClimbA = map(100, 110, 0, 0, 255); // Can change the speed accordingly
  motorClimbB = map(100, 110, 0, 0, 255); // Can change the speed accordingly
  
  sClaw.write(clawValue); // Send PWM signal to claw servo motor
  sJoint.write(jointValue); // Send PWM signal to joint servo motor
  analogWrite(enA, motorSpeedA); // Send PWM signal to motor A
  analogWrite(enB, motorSpeedB); // Send PWM signal to motor B
  analogWrite(A0, motorClimbA); // Send PWM signal to motor A
  analogWrite(A1, motorClimbB); // Send PWM signal to motor B
}
void resetData() {
  // Reset the values when there is no radio connection - Set initial default values
  data.j1PotX = 127;
  data.j1PotY = 127;
  data.j2PotX = 127;
  data.j2PotY = 127;
  data.j1Button = 1;
  data.pot1 = 1;
  data.j2Button = 1;
  data.pot2 = 1;
  data.tSwitch1 = 1;
  data.tSwitch2 = 1;
}

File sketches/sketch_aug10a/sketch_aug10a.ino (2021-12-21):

// MPU-6050 Accelerometer + Gyro
// -----------------------------
//
// By arduino.cc user "Krodal".
//
// June 2012
//      first version
// July 2013
//      The 'int' in the union for the x,y,z
//      changed into int16_t to be compatible
//      with Arduino Due.
//
// Open Source / Public Domain
//
// Using Arduino 1.0.1
// It will not work with an older version,
// since Wire.endTransmission() uses a parameter
// to hold or release the I2C bus.
//
// Documentation:
// - The InvenSense documents:
//   - "MPU-6000 and MPU-6050 Product Specification",
//     PS-MPU-6000A.pdf
//   - "MPU-6000 and MPU-6050 Register Map and Descriptions",
//     RM-MPU-6000A.pdf or RS-MPU-6000A.pdf
//   - "MPU-6000/MPU-6050 9-Axis Evaluation Board User Guide"
//     AN-MPU-6000EVB.pdf
//
// The accuracy is 16-bits.
//
// Temperature sensor from -40 to +85 degrees Celsius
//   340 per degrees, -512 at 35 degrees.
//
// At power-up, all registers are zero, except these two:
//      Register 0x6B (PWR_MGMT_2) = 0x40  (I read zero).
//      Register 0x75 (WHO_AM_I)   = 0x68.
//
 
#include <Wire.h>
 
 
// The name of the sensor is "MPU-6050".
// For program code, I omit the '-',
// therefor I use the name "MPU6050....".
 
 
// Register names according to the datasheet.
// According to the InvenSense document
// "MPU-6000 and MPU-6050 Register Map
// and Descriptions Revision 3.2", there are no registers
// at 0x02 ... 0x18, but according other information
// the registers in that unknown area are for gain
// and offsets.
//
#define MPU6050_AUX_VDDIO          0x01   // R/W
#define MPU6050_SMPLRT_DIV         0x19   // R/W
#define MPU6050_CONFIG             0x1A   // R/W
#define MPU6050_GYRO_CONFIG        0x1B   // R/W
#define MPU6050_ACCEL_CONFIG       0x1C   // R/W
#define MPU6050_FF_THR             0x1D   // R/W
#define MPU6050_FF_DUR             0x1E   // R/W
#define MPU6050_MOT_THR            0x1F   // R/W
#define MPU6050_MOT_DUR            0x20   // R/W
#define MPU6050_ZRMOT_THR          0x21   // R/W
#define MPU6050_ZRMOT_DUR          0x22   // R/W
#define MPU6050_FIFO_EN            0x23   // R/W
#define MPU6050_I2C_MST_CTRL       0x24   // R/W
#define MPU6050_I2C_SLV0_ADDR      0x25   // R/W
#define MPU6050_I2C_SLV0_REG       0x26   // R/W
#define MPU6050_I2C_SLV0_CTRL      0x27   // R/W
#define MPU6050_I2C_SLV1_ADDR      0x28   // R/W
#define MPU6050_I2C_SLV1_REG       0x29   // R/W
#define MPU6050_I2C_SLV1_CTRL      0x2A   // R/W
#define MPU6050_I2C_SLV2_ADDR      0x2B   // R/W
#define MPU6050_I2C_SLV2_REG       0x2C   // R/W
#define MPU6050_I2C_SLV2_CTRL      0x2D   // R/W
#define MPU6050_I2C_SLV3_ADDR      0x2E   // R/W
#define MPU6050_I2C_SLV3_REG       0x2F   // R/W
#define MPU6050_I2C_SLV3_CTRL      0x30   // R/W
#define MPU6050_I2C_SLV4_ADDR      0x31   // R/W
#define MPU6050_I2C_SLV4_REG       0x32   // R/W
#define MPU6050_I2C_SLV4_DO        0x33   // R/W
#define MPU6050_I2C_SLV4_CTRL      0x34   // R/W
#define MPU6050_I2C_SLV4_DI        0x35   // R  
#define MPU6050_I2C_MST_STATUS     0x36   // R
#define MPU6050_INT_PIN_CFG        0x37   // R/W
#define MPU6050_INT_ENABLE         0x38   // R/W
#define MPU6050_INT_STATUS         0x3A   // R  
#define MPU6050_ACCEL_XOUT_H       0x3B   // R  
#define MPU6050_ACCEL_XOUT_L       0x3C   // R  
#define MPU6050_ACCEL_YOUT_H       0x3D   // R  
#define MPU6050_ACCEL_YOUT_L       0x3E   // R  
#define MPU6050_ACCEL_ZOUT_H       0x3F   // R  
#define MPU6050_ACCEL_ZOUT_L       0x40   // R  
#define MPU6050_TEMP_OUT_H         0x41   // R  
#define MPU6050_TEMP_OUT_L         0x42   // R  
#define MPU6050_GYRO_XOUT_H        0x43   // R  
#define MPU6050_GYRO_XOUT_L        0x44   // R  
#define MPU6050_GYRO_YOUT_H        0x45   // R  
#define MPU6050_GYRO_YOUT_L        0x46   // R  
#define MPU6050_GYRO_ZOUT_H        0x47   // R  
#define MPU6050_GYRO_ZOUT_L        0x48   // R  
#define MPU6050_EXT_SENS_DATA_00   0x49   // R  
#define MPU6050_EXT_SENS_DATA_01   0x4A   // R  
#define MPU6050_EXT_SENS_DATA_02   0x4B   // R  
#define MPU6050_EXT_SENS_DATA_03   0x4C   // R  
#define MPU6050_EXT_SENS_DATA_04   0x4D   // R  
#define MPU6050_EXT_SENS_DATA_05   0x4E   // R  
#define MPU6050_EXT_SENS_DATA_06   0x4F   // R  
#define MPU6050_EXT_SENS_DATA_07   0x50   // R  
#define MPU6050_EXT_SENS_DATA_08   0x51   // R  
#define MPU6050_EXT_SENS_DATA_09   0x52   // R  
#define MPU6050_EXT_SENS_DATA_10   0x53   // R  
#define MPU6050_EXT_SENS_DATA_11   0x54   // R  
#define MPU6050_EXT_SENS_DATA_12   0x55   // R  
#define MPU6050_EXT_SENS_DATA_13   0x56   // R  
#define MPU6050_EXT_SENS_DATA_14   0x57   // R  
#define MPU6050_EXT_SENS_DATA_15   0x58   // R  
#define MPU6050_EXT_SENS_DATA_16   0x59   // R  
#define MPU6050_EXT_SENS_DATA_17   0x5A   // R  
#define MPU6050_EXT_SENS_DATA_18   0x5B   // R  
#define MPU6050_EXT_SENS_DATA_19   0x5C   // R  
#define MPU6050_EXT_SENS_DATA_20   0x5D   // R  
#define MPU6050_EXT_SENS_DATA_21   0x5E   // R  
#define MPU6050_EXT_SENS_DATA_22   0x5F   // R  
#define MPU6050_EXT_SENS_DATA_23   0x60   // R  
#define MPU6050_MOT_DETECT_STATUS  0x61   // R  
#define MPU6050_I2C_SLV0_DO        0x63   // R/W
#define MPU6050_I2C_SLV1_DO        0x64   // R/W
#define MPU6050_I2C_SLV2_DO        0x65   // R/W
#define MPU6050_I2C_SLV3_DO        0x66   // R/W
#define MPU6050_I2C_MST_DELAY_CTRL 0x67   // R/W
#define MPU6050_SIGNAL_PATH_RESET  0x68   // R/W
#define MPU6050_MOT_DETECT_CTRL    0x69   // R/W
#define MPU6050_USER_CTRL          0x6A   // R/W
#define MPU6050_PWR_MGMT_1         0x6B   // R/W
#define MPU6050_PWR_MGMT_2         0x6C   // R/W
#define MPU6050_FIFO_COUNTH        0x72   // R/W
#define MPU6050_FIFO_COUNTL        0x73   // R/W
#define MPU6050_FIFO_R_W           0x74   // R/W
#define MPU6050_WHO_AM_I           0x75   // R
 
 
// Defines for the bits, to be able to change
// between bit number and binary definition.
// By using the bit number, programming the sensor
// is like programming the AVR microcontroller.
// But instead of using "(1<<X)", or "_BV(X)",
// the Arduino "bit(X)" is used.
#define MPU6050_D0 0
#define MPU6050_D1 1
#define MPU6050_D2 2
#define MPU6050_D3 3
#define MPU6050_D4 4
#define MPU6050_D5 5
#define MPU6050_D6 6
#define MPU6050_D7 7
 
// AUX_VDDIO Register
#define MPU6050_AUX_VDDIO MPU6050_D7  // I2C high: 1=VDD, 0=VLOGIC
 
// CONFIG Register
// DLPF is Digital Low Pass Filter for both gyro and accelerometers.
// These are the names for the bits.
// Use these only with the bit() macro.
#define MPU6050_DLPF_CFG0     MPU6050_D0
#define MPU6050_DLPF_CFG1     MPU6050_D1
#define MPU6050_DLPF_CFG2     MPU6050_D2
#define MPU6050_EXT_SYNC_SET0 MPU6050_D3
#define MPU6050_EXT_SYNC_SET1 MPU6050_D4
#define MPU6050_EXT_SYNC_SET2 MPU6050_D5
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

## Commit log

2021-04-29 Schematic and PCB design of flight control that we will use
    [Flight Controller PCB.brd, Flight Controller Schematic.sch]
2021-04-29 Rename Flight Controller PCB.brd to Boards/Flight Controller PCB.brd
    [Flight Controller PCB.brd]
2021-04-29 Rename Flight Controller Schematic.sch to Boards/Flight Controller Schematic.sch
    [Flight Controller Schematic.sch]
2021-12-21 Rename Boards/Flight Controller PCB.brd to Electronics/Flight Controller PCB.brd
    [Flight Controller PCB.brd]
2021-12-21 Rename Boards/Flight Controller Schematic.sch to Electronics/Flight Controller Schematic.sch
    [Flight Controller Schematic.sch]
2021-12-21 Rename Electronics/Flight Controller PCB.brd to Electronics/Flight Controller/Flight Control Unit PCB.brd
    [Flight Control Unit PCB.brd]
2021-12-21 Rename Electronics/Flight Controller Schematic.sch to Electronics/Flight Controller/Flight control unit Schematic.sch
    [Flight control unit Schematic.sch]
2021-12-21 added skylark package
    [Link_1.STL, Link_2.STL, Link_3.STL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]

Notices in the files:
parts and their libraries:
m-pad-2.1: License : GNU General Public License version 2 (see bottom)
